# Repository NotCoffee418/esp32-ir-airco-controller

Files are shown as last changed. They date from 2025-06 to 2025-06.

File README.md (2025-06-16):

# ESP32 IR Air Conditioner Controller

A WiFi-enabled ESP32 device that controls Fujitsu air conditioners via infrared commands. Features a web dashboard for manual control, REST API for automation, and automatic WiFi fallback with hotspot configuration.

## What it does

This device replaces your physical AC remote with wireless control:
- **Manual Control**: Web dashboard with temperature, mode, fan speed, and swing controls
- **API Integration**: REST endpoints for home automation systems
- **Status Monitoring**: Real-time temperature readings and AC status
- **WiFi Management**: Automatic hotspot fallback when WiFi connection fails
- **API Key Management**: Secure API access with key generation and management

## Supported AC Models

Tested and confirmed working with:
- **ASHG24KMTA** (24,000 BTU unit) with AR-REW2E remote (0.5°C steps)
- **ASHG09KMCC** (9,000 BTU unit) with AR-REB1E remote (1°C steps)

Uses ARREB1E remote protocol for both units. The project can be modified to support other Fujitsu models or different AC brands by updating the IR command codes.

## Hardware Requirements

📋 **[Complete Shopping List](docs/shopping-list.md)** - All components with supplier links

🔌 **[Pin Layout Guide](docs/module-pins.md)** - Wiring connections and schematic

📦 **[3D Printable Case](models/AircoControllerCase.stl)** - Custom enclosure design

## Software Setup

### Prerequisites
- Visual Studio Code with PlatformIO extension
- ESP32 connected via USB

### Installation
1. **Open Project**: Use PlatformIO Home → Open Project (important: don't just open the folder in VSCode)
2. **Flash Device**: Press `Ctrl+Shift+P` → "PlatformIO: Upload and Monitor"
3. **Monitor Output**: Watch terminal for hotspot credentials and IP information

### Optional Pre-Configuration
Create `airco-controller/data/config.json` based on `airco-controller/data/config_example.json` to flash the device with WiFi credentials and settings pre-configured.

## WiFi & Network Setup

### Automatic Hotspot Fallback
- **Triggers**: No WiFi config OR WiFi connection lost for >30 seconds
- **Hotspot Name & PIN**: Printed on device bottom + shown in terminal during flashing
- **Access Point**: Connect to hotspot and navigate to `192.168.255.1`
- **Dashboard**: Configure WiFi and access all device features

### Normal Operation
Once WiFi is configured, access the dashboard at the device's local IP address (shown in terminal/hotspot setup).

## Web Dashboard Features

- **Manual Controls**: Set temperature, mode (Cool/Heat/Dry/Fan), fan speed, swing, and powerful mode
- **Status Display**: Current temperature, AC state, WiFi connection info
- **API Key Management**: Generate, view, and delete API keys for automation access
- **Quick Actions**: One-click summer/winter mode presets

## REST API

**[Complete API Documentation](https://github.com/NotCoffee418/esp32-ir-airco-controller/blob/main/docs/api-documentation.md)** - Full endpoint reference with examples

Key endpoints:
- `POST /api/ir/off` - Turn off AC
- `POST /api/ir/on` - Turn on with settings (mode, temp, fan, swing)
- `POST /api/ir/toggle-powerful` - Toggle powerful mode
- `GET /api/sensors` - Get temperature and mode status (no auth required)

All control endpoints require API key authentication:
```
Authorization: ApiKey YOUR_API_KEY
```

Generate and manage API keys through the web dashboard.

## Project Structure

- **`airco-controller/`** - Main ESP32 firmware (flash this to your device)
- **`ir-receiver/`** - Test module for capturing IR signals from remotes
- **`docs/`** - Hardware guides and component lists  
- **`models/`** - 3D printable case files

## IR Receiver Test Module

The `ir-receiver/` folder contains a simple test program to capture and decode IR signals from your existing AC remote. Useful for:
- Verifying hardware connections
- Adding support for new AC models
- Debugging IR transmission issues

Flash this first if you want to test your hardware setup before installing the main controller.

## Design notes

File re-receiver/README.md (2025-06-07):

# RE-Receiver

Experimental tool to test and verify IR signals.
Interpret IR signals and display them on a web page. Designed for Fujitsu A/C units.

## Usage

1. PlatformIO vscode extension installed.
2. Configure `data/config.ini` with your WiFi credentials and network settings.
3. Create file system and upload code

    ```bash
    # Only do this once unless full reset
    pio run --target uploadfs
    ```

4. Ctrl+Shift+P -> PlatformIO: Upload and Monitor

## Modules

### TSOP2238 (front view) → ESP32

- Pin 1 (OUT) → GPIO 4
- Pin 2 (VS)  → 3.3V
- Pin 3 (GND) → GND

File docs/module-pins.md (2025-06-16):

# ESP32 AC Controller - Module Connections

## ⚠️ CRITICAL WARNING ⚠️

**ALWAYS VERIFY PIN LAYOUTS WITH THE COMPONENT DATASHEET BEFORE CONNECTING!**

Different manufacturers and model revisions can have completely different pin arrangements, even for components with the same part number. Double-check your specific component's datasheet to avoid damaging your ESP32 or components. When in doubt, use a multimeter to verify connections.

---

## Temperature Sensor

**DS18B20 Waterproof Digital Temperature Sensor**  
[Gotron DS18B20](https://www.gotron.be/waterproof-ds18b20-digital-temperature-sensor-extras.html)

**Connections:**
- Blue wire → GND
- Red wire → VIN (3.3V)
- Yellow wire → D13
- **4.7kΩ pull-up resistor between Red and Yellow wires**

**Soldering Configuration:**
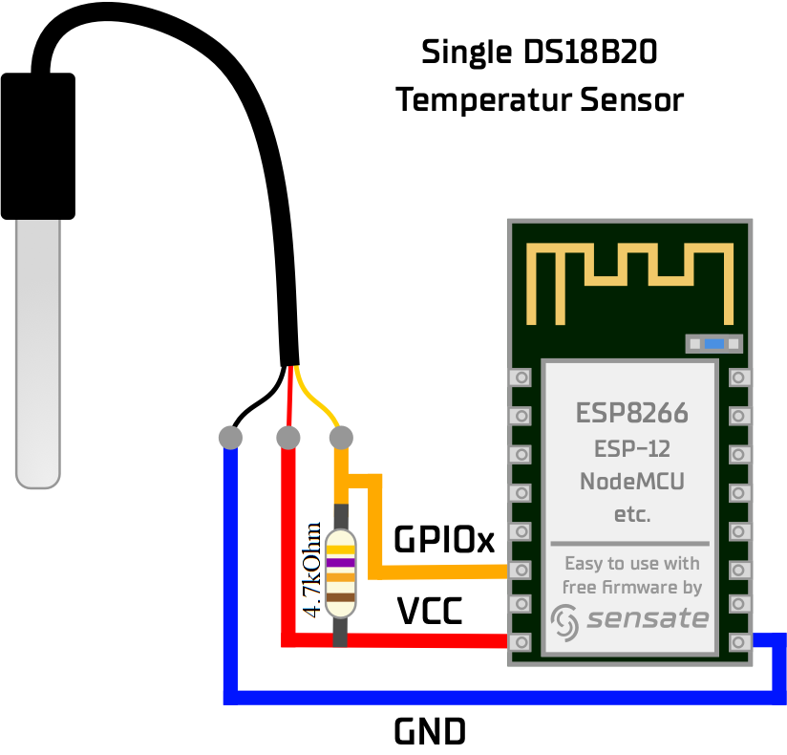
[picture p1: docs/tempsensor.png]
Temperature Sensor Wiring


*The pull-up resistor must be soldered between the red (VIN) and yellow (data) wires as shown above.*

## IR LED Transmitter

**ELIR204 IR LED (940nm, 3mm)**  
[Gotron IR LED](https://www.gotron.be/componenten/actief/opto/zender-ontvanger/ir-led-blauw-35-3mm-940nm-20ma-1-2v.html)

**Connections:**
- Long leg (Anode) → D4 (via 100Ω resistor)
- Short leg (Cathode) → GND

## Mode Switch

**MS100A SPST Toggle Switch (6A, 250V)**  
[Gotron Toggle Switch](https://www.gotron.be/componenten/schakelmat/schakelaars/toestel/toestelschakelaar-enkelpolig-on-off-spst-6a-250v-zwart.html)

**Connections:**
- Pin 1 → GND
- Pin 2 → D12

---

## Ground Connection Notes

**All GND connections from the modules can be combined using:**
- WAGO 5-pole connectors for clean, reusable connections
- Direct soldering for permanent installations

This allows sharing a single GND connection from the ESP32 to all modules requiring ground.

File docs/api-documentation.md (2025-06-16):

# AC Controller API Documentation

## Authentication

Control endpoints require API key authentication:

```
Authorization: ApiKey YOUR_API_KEY
```

API keys can be generated on the device's web dashboard.

**Note:** `/api/sensors` does not require authentication.

## Response Format

**IR Control endpoints** return:
```json
{
  "success": true|false,
  "error": "error message or empty string",
  "data": true|false
}
```

- **data**: `true` = command executed (automatic mode), `false` = command acknowledged but not executed (manual mode)

**Data endpoints** return:
```json
{
  "success": true|false,
  "error": "error message or empty string", 
  "data": { ... }
}
```

## Endpoints

### Turn Off AC

`POST /api/ir/off`

No request body required.

---

### Turn On AC

`POST /api/ir/on`

**Request:**
```json
{
  "mode": 1,
  "fanSpeed": 0,
  "temperature": 23,
  "swing": 1
}
```

**Parameters:**
- **mode** (integer, required):
  - `1`: Cool
  - `2`: Dry (ignores temperature)
  - `3`: Fan (ignores temperature)
  - `4`: Heat
- **fanSpeed** (integer, required):
  - `0`: Auto, `1`: High, `2`: Medium, `3`: Low, `4`: Quiet
- **temperature** (number, required):
  - Cool mode: 18-30°C
  - Heat mode: 16-30°C
  - Dry/Fan modes: ignored
- **swing** (integer, required):
  - `0`: Off, `1`: Vertical

---

### Toggle Powerful Mode

`POST /api/ir/toggle-powerful`

No request body required.

---

### Get Sensor Data

`GET /api/sensors`

**Response:**
```json
{
  "success": true,
  "error": "",
  "data": {
    "temperature": 22.5,
    "isAutomaticMode": true
  }
}
```

## HTTP Status Codes

- **200**: Success
- **400**: Invalid request data
- **401**: Authentication required

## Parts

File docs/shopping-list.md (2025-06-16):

# Shopping List - ESP32 AC Controller (2 Units)

## Microcontroller

**2x NodeMCU ESP32 with USB-C** - €15.90 each  
[Gotron ESP32-C](https://www.gotron.be/esp32-joyit-met-usb-c.html) | [Pin Layout](https://joy-it.net/en/products/SBC-NodeMCU-ESP32-C) | [Manual](https://joy-it.net/files/files/Produkte/SBC-NodeMCU-ESP32-C/SBC-NodeMCU-ESP32-C_Manual-EN_2025-01-17.pdf)

## IR Components

**2x ELIR204 IR LED (940nm, 3mm)** - €0.36 each  
[Gotron IR LED](https://www.gotron.be/componenten/actief/opto/zender-ontvanger/ir-led-blauw-35-3mm-940nm-20ma-1-2v.html)

**2x 100Ω Resistors (1/4W)** - €0.10 each  
[Gotron 100Ω](https://www.gotron.be/ra100-weerstand-1-4w-100-ohm-koolstoffilmlaag.html)  
*Note: Install on positive side only*

## Temperature Sensing

**2x DS18B20 Waterproof Temperature Sensor (includes 4.7kΩ pull-up resistor)** - €11.91 each  
[Gotron DS18B20](https://www.gotron.be/waterproof-ds18b20-digital-temperature-sensor-extras.html)

**2x 4.7kΩ Pull-up Resistors (1/4W)** - €0.10 each  
[Gotron 4.7kΩ](https://www.gotron.be/ra4k7-weerstand-1-4w-4-7-kohm-koolstoffilmlaag.html)  
*Note: Included with DS18B20 sensors at Gotron*

**2x Cable Gland PG7 (Black)** - €0.64 each  
[Gotron Cable Gland](https://www.gotron.be/kabelwartel-zwart-pg7.html)

## Mode Switch

**2x SPST Toggle Switch MS100A (6A, 250V)** - €1.50 each  
[Gotron Toggle Switch](https://www.gotron.be/componenten/schakelmat/schakelaars/toestel/toestelschakelaar-enkelpolig-on-off-spst-6a-250v-zwart.html)

**1x Set Spade Connectors Female 4.8mm (Blue, 10pcs)** - €2.00  
[Gotron Spade Connectors](https://www.gotron.be/opschuifcontact-vrouwelijk-4-8x0-8mm-blauw-10-stuks.html)

## Power Supply

**2x USB Wall Adapter (4W)** - €5.00 each  
[Gotron USB Adapter](https://www.gotron.be/energie/voedingen/gestabiliseerd/usb/usb-voeding-4w.html)  
*Or use any USB adapter you have available*

## Wiring & Connections

**3x Jumper Wire Sets (Female-Female, 15cm, Purple, 10pcs)** - €4.76 each  
[Gotron Jumper Wires](https://www.gotron.be/jumper-wire-paars-female-female-lengte-15cm-10-stuks.html)

**2x WAGO 5-Pole Connector (0.2-4mm², 32A)** - €0.93 each  
[Gotron WAGO Connector](https://www.gotron.be/installatie/installatiemat/verbindingsmateriaal/lusterklemmen/wago-connector-5-polig-0-2-4mm-32a-400v.html)  
*For shared ground connections*

## Hardware

**1x Self-Tapping Screws 2.2x6.5mm (100pcs)** - €5.40  
[Gotron Screws](https://www.gotron.be/installatie/montage/verbindingsmat/diverse/zelftappende-schroef-2-2x6-5mm-100st.html)  
*Plenty for multiple mounting configurations*

---

## Build Notes

- **Quantity**: This list provides components for **2 complete units**
- **IR Range**: ELIR204 LEDs provide sufficient range for typical room installations
- **Power**: USB-C powered units can be powered from any USB adapter or power bank
- **Temperature Sensor**: Waterproof DS18B20 allows external mounting for accurate readings
- **Mode Switch**: Manual/Auto operation toggle for each unit

---

## Total Cost

**Component Breakdown:**
- 2x ESP32 NodeMCU: €31.80
- 2x IR LEDs: €0.72
- 2x 100Ω Resistors: €0.20
- 2x DS18B20 Sensors: €23.82
- 2x 4.7kΩ Resistors: €0.20
- 2x Cable Glands: €1.28
- 2x Toggle Switches: €3.00
- 1x Spade Connectors: €2.00
- 2x USB Adapters: €10.00
- 3x Jumper Wire Sets: €14.28
- 2x WAGO Connectors: €1.86
- 1x Self-Tapping Screws: €5.40

**Total: €94.56**

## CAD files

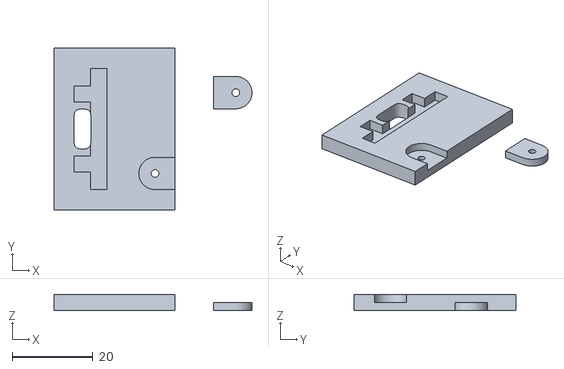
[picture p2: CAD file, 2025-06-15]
models/test_slot_fitting_print.stl
49.0 x 40.0 x 4.00

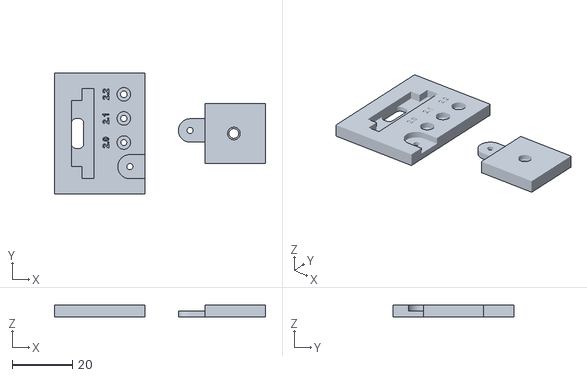
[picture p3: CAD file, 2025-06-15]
models/test3_slot_fitting_print.stl
70.0 x 40.0 x 4.00

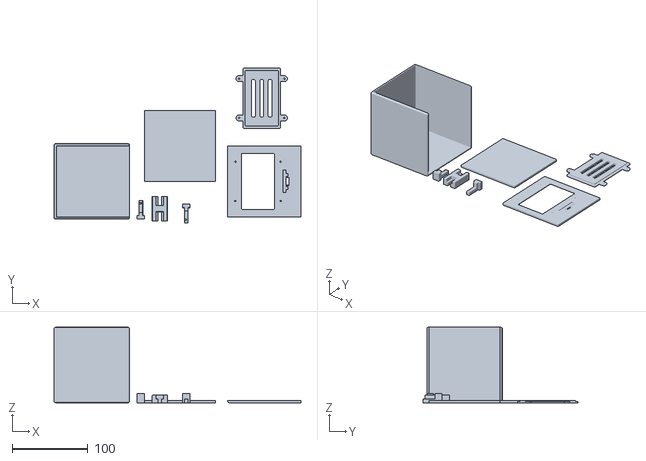
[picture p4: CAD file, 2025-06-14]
models/AircoControllerCase.stl
327.0 x 205.0 x 100.0

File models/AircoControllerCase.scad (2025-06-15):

// FOR FUTURE REFERENCE:
// Don't use OpenSCAD. Software keeps crashing, HQ previews which you need to see holes, are very slow once the model gets bigger.
// Syntax is nice, but everything still quickly turns into a mess.
// CadQuery seems to be the best alternative.

// variable to toggle between printable rotations and visual representation for braining
IS_ASSEMBLED_VIEW = false;

// Disassembles back cover if in assembly view and true
DISASSEMBLE_BACK_COVER = true;

// beginning of board rest levels relative to case floor
board_rest_floor_diff = 20;

// Wall thickness (careful changing this)
wall_thickness = 4;

// USB slot hole size
usbc_slot_width = 9.88;
usbc_slot_height = 4.1;

// Screw hole size (for 6.5mm x 2.2mm with head 1.5)
screw_hole_depth = 7;
screw_head_depth = 1.8;
screw_head_radius = 4.5 / 2; // with 0.4 spacing



// 2.0: resin breaks at regular hole
// 2.05: resin breaks at backplate clip
// 2.1: resin tight fit
// 2.2: resin good
// presumable PLA holes shrink even further, but less breaky.
// Actual screw max diameter seems to be 2.10, and if holes and we can probably handle 0.2 too small in PLA(?)
screw_hole_radius = 2.1 / 2; // resin bre


// Mount block sizes
screw_mount_width = 10;
screw_mount_height = 10;

// 0 is valid, just leaves hole in the back and screw may poke out slighly.
// change freely but be careful of overlapping with other parts.
// 0 is good for checking if hole is positioned right and avoiding weird print issues at angles.
mount_block_back_padding = 0;

// Back cover
back_cover_width = 80;
back_cover_height = 50; // without clips but including cover spacing


// Board actual size
board_width = 28.4;
board_depth = 51.4; // without usbc overhang
board_height = 1.5;

// amount the USBC port sticks out of the board
usbc_port_overhang = 1.5;


// How deep does the device holder slide?
device_holder_single_slot_depth = 12;



// Case Shell without right side
if (!IS_ASSEMBLED_VIEW) {
	// Outer case without floor and back
	translate([0,100,0]) {
	rotate([180,270,0]) {
			outer_case_without_floor_and_back_side();
		}
	}

	// Floor
	translate([120, 50, 0]) {
		floor();
	}

	// case back side
	translate([230,0,0]) {
		outer_case_back_side(); // mind the rounded side!
	}

	// Case removable back cover
	translate([320, 120, 0]) {
		rotate([180, 0, 90]) {
			back_panel_cover();
		}
	}

	// Device holder unit right
	translate([110, 0-30, device_holder_single_slot_depth]) {
		rotate([270, 0, 0]) {
			device_holder_unit(false);
		}
	}

	// Device holder slider bottom
	translate([140, 0, 10]) {
		rotate([180, 0, 0]) {
			device_holder_slider_bottom();
		}
	}

	// Device holder unit left
	translate([180, 20-30, 0]) {
		rotate([90, 0, 0]) {
			device_holder_unit(true);
		}
	}

} else { // Assembled view
	//Outer case without floor and back
	translate([100, 0, 100]) {
		rotate([0, 90, 90]) { 
			outer_case_without_floor_and_back_side();
		}
	}

	// Floor
	translate([wall_thickness , wall_thickness, 0]) {
		floor();
	}

	// case back side
	translate([0,100,100]) {
		rotate([90, 90, 0]) {
			outer_case_back_side(); // mind the rounded side!
		}
	}

	// Case removable back cover
	if (DISASSEMBLE_BACK_COVER) {
		translate([200, 0, 0]) {
			rotate([0, 0, 90]) {
				back_panel_cover();
			}
		}
	} else {
		translate([6, 100, 35]) {
			rotate([90, 0, 0]) {
				back_panel_cover();
			}
		}
	}
	

	// Assembled device holder and spoof board
	translate([34.92,57.1,0]) {
		rotate([0,0,270]) {
			assembled_device_holder(true);
		}		
	}
}


//test_print_pieces();


module floor() {
	center = 100 / 2;

	// Distance from center of case to mount block
	// 0 should be center, 50 should just outside of case
	// this is reference for correct case holes.
	center_offset_pos = 25;

	// Floor
	difference() {
		// Floor block
		cube([100-wall_thickness*2,100-wall_thickness*2,wall_thickness]);

		// Screw hole device mount 1
		// lazy measure
		translate([
			47.07,
			56.6,
			wall_thickness]
		) {
			rotate([180,0,0]) {
				screw_head_hole();
			}
		}

		// Screw hole device mount 2
		// lazy measure
		translate([
			47.07,
			29.6,
			wall_thickness]
		) {
			rotate([180,0,0]) {
				screw_head_hole();
			}
		}		
	}

	

	// Mount block - right frontish
	translate([100-wall_thickness*2, center-center_offset_pos - screw_mount_width, wall_thickness]) {
		rotate([0, 0, 90]) {
			screw_mount_block();
		}
	}

	// Mount block - right side backish
	translate([100-wall_thickness*2, center+center_offset_pos-screw_mount_width+wall_thickness/2, wall_thickness]) {
		rotate([0, 0, 90]) {
			screw_mount_block();
		}
	}

	// Mount block - left side frontish
	translate([0, center - center_offset_pos, wall_thickness]) {
		rotate([0, 0, 270]) {
			screw_mount_block();
		}
	}


	// Mount block - left side backish
	translate([0, center + center_offset_pos + wall_thickness/2, wall_thickness]) {
		rotate([0, 0, 270]) {
			screw_mount_block();
		}
	}

	// Mount block - back side rightish
	translate([center-center_offset_pos, 100-wall_thickness*2, wall_thickness]) {
		rotate([0, 0, 180]) {
			screw_mount_block();
		}
	}

	// Mount block - back side left
	translate([center+center_offset_pos+wall_thickness/2, 100-wall_thickness*2, wall_thickness]) {
		rotate([0, 0, 180]) {
			screw_mount_block();
		}
	}

}



// 8 wide
// with_difference_hole: 
// true: simulates a screw (used to difference in case)
// false: actual hole as visible
module backplate_screw_hole_holder(x, y, z, with_difference_hole=true) {
	case_clip_width = 8;
	plate_clip_width = 7.6;
	clip_width = with_difference_hole ? plate_clip_width : case_clip_width;
	x_offset = !with_difference_hole ? 0 : (case_clip_width - plate_clip_width) / 2;

	translate([x+x_offset,y+5,z]) {
		linear_extrude(height=wall_thickness/2) { 
			difference() {
				union() {
					square([clip_width, 5.5]); // Attahment clip square part
					translate([clip_width/2, 0, 0]) // Attachment clip round part
						circle(r=clip_width/2, $fn=100);

				}
				if (with_difference_hole) {
					translate([clip_width/2, 0, 0])
						circle(r=screw_hole_radius, $fn=50); // Screw hole
				}
			}
			
		}
		if (!with_difference_hole) {
			translate([clip_width/2, 0, 0]) {
				linear_extrude(height=wall_thickness) {
					circle(r=screw_hole_radius, $fn=50); // Screw hole
				}
			}
		}
	}
}


// is_true_panel: true: actual panel, false: difference hole
module back_panel_cover(is_true_panel=true) {
	cover_slot_spacing = 3;
	corner_radius = 1.5;
	layer_height = wall_thickness/2;

	clearance_offset = 0.4;

	size_offset = is_true_panel ? clearance_offset : 0;
	
	translate([cover_slot_spacing+corner_radius/2,0,0]) { // dontk now why, dont care.
		difference() {
			// Back cover panel
			union() {
				// Outer Layer
				rounded_square_wall(
					[size_offset/2, size_offset/2, 0], 
					[back_cover_width-size_offset, back_cover_height-size_offset, layer_height], 
					corner_radius); // bot layer (bigger)

				// Inner Layer
				// Hide on true cover, but use for difference hole
				if (!is_true_panel) {
					rounded_square_wall(
						[cover_slot_spacing, cover_slot_spacing, layer_height],
						[back_cover_width-cover_slot_spacing*2, back_cover_height-cover_slot_spacing*2,layer_height], 
						corner_radius); // top layer
				}
				backplate_screw_hole_holder(10, -10, 0, is_true_panel);
				backplate_screw_hole_holder(62, -10, 0, is_true_panel);
				translate([80, 60, 0]) {
					rotate([0, 0, 180]) {
						backplate_screw_hole_holder(10, 0, 0, is_true_panel);
						backplate_screw_hole_holder(62, 0, 0, is_true_panel);
					}
				}
			}
			// Air vents
			if (is_true_panel) {
				union() {
					translate([15,11.5,0]) {
						air_vent();
					}
					translate([15,22.5,0]) {
						air_vent();
					}
					translate([15,33.5,0]) {
						air_vent();
					}
				}
			}
		}
	}
}


module outer_case_without_floor_and_back_side() {
	
	// Mount screw hole relative positions
	screw_hole_pos_and_rot = get_mount_screw_head_hole_pos_and_rot();
	shx = screw_hole_pos_and_rot[0][0];
	shy = screw_hole_pos_and_rot[0][1];
	shz = screw_hole_pos_and_rot[0][2];
	shrotx = screw_hole_pos_and_rot[1][0];
	shroty = screw_hole_pos_and_rot[1][1];
	shrotz = screw_hole_pos_and_rot[1][2];

	center = 100 / 2;

	// why 1? no clue, but it works.
	screw_pos_center_offset = 25 + 1;

	difference() {
		// Box boxy
		rounded_cube([100, 100, 100], 2);

		// Inner cavity 3mm wall thickness
		translate([wall_thickness, wall_thickness, wall_thickness])
			cube([100-wall_thickness, 100-wall_thickness*2, 100-wall_thickness]);


		// Screw holes right side (front sided)
		translate([100-wall_thickness-shx, shy, center-screw_pos_center_offset]) {
			rotate([shrotx, shroty, shrotz]) {
				screw_head_hole();
			}
		}

		// Screw holes right side (back sided)
		translate([100-wall_thickness-shx, shy, center+screw_pos_center_offset]) {
			rotate([shrotx, shroty, shrotz]) {
				screw_head_hole();
			}
		}
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

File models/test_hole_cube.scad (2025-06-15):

screw_hole_radius = 1.9 / 2;

difference() {
	rounded_cube([20,20,20],3);
	translate([10,10,0]) {
		screw_hole(20);
	}
	rotate([0, 90, 0]) {
		translate([-10,10,0]) {
			screw_hole(20);
		}
	}

	rotate([0, 90, 90]) {
		translate([-10,-10,0]) {
			screw_hole(20);
		}
	}	
}

module screw_hole(depth) {
	linear_extrude(height=depth) {
		circle(r=screw_hole_radius, $fn=20);
	}
}

module rounded_cube(size, radius) {
    translate([radius, radius, radius])  // shift to correct position
        minkowski() {
            cube([size[0]-2*radius, size[1]-2*radius, size[2]-2*radius]);
            sphere(r=radius, $fn=50*radius);
        }
}

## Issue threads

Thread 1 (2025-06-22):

IR signals break on dry mode

NotCoffee418, 2025-06-22:
Attempting to set AC to dry prevents new IR signals from sending until box is restarted.
Likely some sort of soft crash from disallowed settings (any temperature defined?) causing it to think we are still emitting signal.
Possibly coincidence, but we'll find out if it's consistently a problem.

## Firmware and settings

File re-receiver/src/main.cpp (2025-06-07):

#include <Arduino.h>
#include <WiFi.h>
#include <WebServer.h>
#include <IRremoteESP8266.h>
#include <IRrecv.h>
#include <IRutils.h>
#include <ArduinoJson.h>
#include <ir_Fujitsu.h>
#include <LittleFS.h>

// WiFi credentials - will be loaded from config.ini
String wifi_ssid = "YOUR_WIFI_SSID";
String wifi_password = "YOUR_WIFI_PASSWORD";
String config_static_ip = "192.168.50.201";
String config_gateway = "192.168.50.1";

// Static IP configuration
IPAddress local_IP(192, 168, 50, 201);
IPAddress gateway(192, 168, 50, 1);      // Usually your router IP
IPAddress subnet(255, 255, 255, 0);
IPAddress primaryDNS(8, 8, 8, 8);       // Google DNS
IPAddress secondaryDNS(8, 8, 4, 4);

// IR receiver setup
const uint16_t IR_RECV_PIN = 4;  // GPIO4
const uint16_t CAPTURE_BUFFER_SIZE = 1024;
const uint8_t TIMEOUT = 50;  // Longer timeout to catch multiple frames
const uint32_t FRAME_COLLECTION_TIME = 3000;  // Collect frames for 3 seconds
unsigned long lastDecodeTime = 0;

IRrecv irrecv(IR_RECV_PIN, CAPTURE_BUFFER_SIZE, TIMEOUT, true);
decode_results results;
WebServer server(80);

// Function prototypes (tells compiler these functions exist)
void handleRoot();
void handleLastSignal();
void handleStatus();
void handleNotFound();
void loadConfig();

// Store last received IR signal with decoded data
struct IRSignal {
    String protocol;
    std::vector<uint64_t> values;
    std::vector<uint16_t> bits;
    String decodedData;
    String modelInfo;
    String rawData;
    unsigned long timestamp;
    bool hasData;
    bool hasDecodedData;
    int frameCount;
} lastSignal = {"", {}, {}, "", "", "", 0, false, false, 0};

void setup() {
    Serial.begin(115200);
    Serial.println("Starting IR HTTP Server...");
    
    // Try to initialize filesystem, but don't worry if it fails
    if (LittleFS.begin(true)) {
        Serial.println("LittleFS mounted successfully");
        loadConfig();
    } else {
        Serial.println("LittleFS not available, using hardcoded defaults");
    }
    
    // If still using defaults, you can hardcode your WiFi here temporarily
    if (wifi_ssid == "YOUR_WIFI_SSID") {
        wifi_ssid = "YourActualSSID";           // Put your real SSID here
        wifi_password = "YourActualPassword";   // Put your real password here
        Serial.println("Using hardcoded WiFi credentials");
    }
    
    // Initialize IR receiver
    irrecv.enableIRIn();
    Serial.println("IR Receiver enabled on GPIO " + String(IR_RECV_PIN));
    
    // Configure static IP
    if (!WiFi.config(local_IP, gateway, subnet, primaryDNS, secondaryDNS)) {
        Serial.println("Failed to configure static IP");
    }
    
    // Connect to WiFi
    WiFi.begin(wifi_ssid.c_str(), wifi_password.c_str());
    Serial.print("Connecting to WiFi: " + wifi_ssid);
    
    while (WiFi.status() != WL_CONNECTED) {
        delay(500);
        Serial.print(".");
    }
    
    Serial.println();
    Serial.println("WiFi connected!");
    Serial.print("IP address: ");
    Serial.println(WiFi.localIP());
    
    // Setup HTTP endpoints
    server.on("/", handleRoot);
    server.on("/last-signal", handleLastSignal);
    server.on("/status", handleStatus);
    server.onNotFound(handleNotFound);
    
    server.begin();
    Serial.println("HTTP server started");
    Serial.println("Endpoints:");
    Serial.println("  GET / - Web interface");
    Serial.println("  GET /last-signal - JSON with last IR signal");
    Serial.println("  GET /status - System status");
}

void loop() {
    // Handle HTTP requests
    server.handleClient();
    
    // Check for IR signals
    if (irrecv.decode(&results)) {
        unsigned long now = millis();
        
        // If this is a new protocol or too much time passed, start fresh  
        if (lastSignal.protocol != typeToString(results.decode_type) || 
            (now - lastDecodeTime) > FRAME_COLLECTION_TIME) {
            
            lastSignal.protocol = typeToString(results.decode_type);
            lastSignal.values.clear();
            lastSignal.bits.clear();
            lastSignal.frameCount = 0;
            lastSignal.rawData = "";
            lastSignal.decodedData = "";
            lastSignal.modelInfo = "";
            lastSignal.hasDecodedData = false;
            Serial.println("=== Starting new IR sequence ===");
        }
        
        // Add this frame to the sequence
        lastSignal.values.push_back(results.value);  // Keep for compatibility
        lastSignal.bits.push_back(results.bits);
        lastSignal.frameCount++;
        lastSignal.hasData = true;
        lastSignal.timestamp = now;
        lastDecodeTime = now;
        
        // Capture FULL hex data from state array (not just results.value)
        String fullHex = "0x";
        for (int i = results.bits / 8 - 1; i >= 0; i--) {  // Big endian
            if (results.state[i] < 16) fullHex += "0";
            fullHex += String(results.state[i], HEX);
        }
        
        // Also create little endian version to compare
        String fullHexLE = "0x";
        for (int i = 0; i < results.bits / 8; i++) {  // Little endian
            if (results.state[i] < 16) fullHexLE += "0";
            fullHexLE += String(results.state[i], HEX);
        }
        
        // Update raw data with full hex
        if (lastSignal.frameCount > 1) lastSignal.rawData += " | ";
        lastSignal.rawData += "Frame" + String(lastSignal.frameCount) + ": " + fullHex + " (" + String(results.bits) + " bits)";
        
        // Print to serial for debugging
        Serial.println("=== IR Frame " + String(lastSignal.frameCount) + " ===");
        Serial.println("Protocol: " + lastSignal.protocol);
        Serial.println("Full Hex BE (" + String(results.bits) + " bits): " + fullHex);
        Serial.println("Full Hex LE (" + String(results.bits) + " bits): " + fullHexLE);
        Serial.println("Partial (results.value): 0x" + String(results.value, HEX));
        Serial.println("Gap since last: " + String(now - lastDecodeTime) + "ms");
        
        // Show byte-by-byte breakdown
        Serial.print("State bytes: ");
        for (uint16_t i = 0; i < results.bits / 8; i++) {
            if (results.state[i] < 16) Serial.print("0");
            Serial.print(results.state[i], HEX);
            Serial.print(" ");
        }
        Serial.println();
        
        // Try to decode EVERY frame as Fujitsu AC to see what the library sees
        if (lastSignal.protocol == "FUJITSU_AC") {
            Serial.println("=== Attempting Fujitsu AC decode on this frame ===");
            
            IRFujitsuAC ac(0);
            if (ac.validChecksum(results.state, results.bits / 8)) {
                ac.setRaw(results.state, results.bits / 8);
                
                Serial.println("DECODE SUCCESS for Frame " + String(lastSignal.frameCount) + ":");
                Serial.println("Power: " + String(ac.getPower() ? "ON" : "OFF"));
                Serial.println("Mode: " + String(ac.getMode()));
                Serial.println("Temperature: " + String(ac.getTemp()) + "°C");
                Serial.println("Fan Speed: " + String(ac.getFanSpeed()));
                Serial.println("Swing: " + String(ac.getSwing()));
                
                // Store the LATEST successful decode
                lastSignal.decodedData = "Power: " + String(ac.getPower() ? "ON" : "OFF") + 
                                       " | Mode: " + String(ac.getMode()) + 
                                       " | Temp: " + String(ac.getTemp()) + "°C" +
                                       " | Fan: " + String(ac.getFanSpeed()) +
                                       " | Swing: " + String(ac.getSwing()) +
                                       " | Model: " + String(ac.getModel()) +
                                       " | Frame: " + String(lastSignal.frameCount);
                
                // Extract model info for web display from the full toString() output
                String fullStateString = ac.toString();
                int modelStart = fullStateString.indexOf("Model: ");
                if (modelStart != -1) {
                    int modelEnd = fullStateString.indexOf(",", modelStart);
                    if (modelEnd != -1) {
                        lastSignal.modelInfo = fullStateString.substring(modelStart + 7, modelEnd); // Skip "Model: "
                    } else {
                        lastSignal.modelInfo = "Model " + String(ac.getModel());
                    }
                } else {
                    lastSignal.modelInfo = "Model " + String(ac.getModel());
                }
                
                lastSignal.hasDecodedData = true;
            } else {
                Serial.println("DECODE FAILED for Frame " + String(lastSignal.frameCount) + " (bad checksum)");
            }
        }
        
        Serial.println();
        
        // Resume receiving
        irrecv.resume();
    }
    
    delay(50);  // Small delay to prevent overwhelming the loop
}

void handleRoot() {
    String html = R"rawliteral(
<!DOCTYPE html>
<html>
<head>
    <title>ESP32 IR Receiver</title>
    <meta name="viewport" content="width=device-width, initial-scale=1">
    <style>
        body { font-family: Arial; margin: 40px; background: #f0f0f0; }
        .container { background: white; padding: 20px; border-radius: 8px; box-shadow: 0 2px 10px rgba(0,0,0,0.1); }
        .signal { background: #e8f4fd; padding: 15px; border-radius: 5px; margin: 10px 0; }
        .decoded { background: #e8f8e8; padding: 12px; border-radius: 5px; margin: 8px 0; border-left: 4px solid #4CAF50; }
        .technical { background: #f8f8f8; padding: 10px; border-radius: 5px; margin: 8px 0; font-family: monospace; font-size: 0.9em; }
        .timestamp { color: #666; font-size: 0.9em; }
        .stats { display: flex; gap: 15px; margin: 10px 0; }
        .stat { background: #fff; padding: 8px 12px; border-radius: 4px; border: 1px solid #ddd; }
        .note { margin-top: 10px; font-size: 0.8em; color: #888; font-style: italic; }
        button { background: #007cba; color: white; border: none; padding: 10px 20px; border-radius: 5px; cursor: pointer; }
        button:hover { background: #005a87; }
    </style>
</head>
<body>
    <div class="container">
        <h1 id="pageTitle">ESP32 IR Receiver</h1>
        <p>Point your remote at the receiver and press any button!</p>
        
        <button onclick="refreshSignal()">Refresh Last Signal</button>
        
        <div id="lastSignal">
            <h3>Last Signal:</h3>
            <div id="signalData">No signal received yet...</div>
        </div>
    </div>

    <script>
        function refreshSignal() {
            fetch('/last-signal')
                .then(response => response.json())
                .then(data => {
                    const signalDiv = document.getElementById('signalData');
                    if (data.hasData) {
                        // Update page title with model info
                        const titleElement = document.getElementById('pageTitle');
                        if (data.modelInfo) {
                            titleElement.textContent = `ESP32 IR Receiver - Fujitsu ${data.modelInfo}`;
                        } else {
                            titleElement.textContent = `ESP32 IR Receiver - ${data.protocol}`;
                        }
                        
                        let html = `
                            <div class="signal">
                                <strong>Protocol:</strong> ${data.protocol}
                                <div class="timestamp">Received: ${new Date(data.timestamp).toLocaleString()}</div>
                            </div>
                        `;
                        
                        if (data.hasDecodedData) {
                            html += `
                                <div class="decoded">
                                    <strong>Decoded AC Settings:</strong><br>
                                    ${data.decodedData.replace(/\|/g, '<br>')}
                                </div>
                            `;
                        }
                        
                        html += `
                            <div class="stats">
                                <div class="stat"><strong>Frames:</strong> ${data.frameCount}</div>
                                <div class="stat"><strong>Frequency:</strong> ${data.frequency || '38kHz'}</div>
                                <div class="stat"><strong>Signal:</strong> ${data.signalStrength || 'Good'}</div>
                                <div class="stat"><strong>Total Bits:</strong> ${data.frames.reduce((sum, frame) => sum + frame.bits, 0)}</div>
                            </div>
                        `;
                        
                        html += `<div class="technical"><strong>Technical Details:</strong><br>`;
                        html += `${data.rawData || 'No raw data available'}<br>`;
                        html += `<br><strong>Frame Breakdown:</strong><br>`;
                        data.frames.forEach((frame, index) => {
                            html += `Frame ${index + 1}: ${frame.valueHex} (${frame.bits} bits - partial view)<br>`;
                        });
                        html += `</div>`;
                        
                        html += `
                            <div class="note">
                                Tip: Try changing temperature, mode, or fan speed on your remote to see live updates!
                            </div>
                        `;
                        
                        signalDiv.innerHTML = html;
                    } else {
                        signalDiv.innerHTML = 'No signal received yet...';
                    }
                })
                .catch(err => console.error('Error:', err));
        }
        
        // Auto-refresh every 2 seconds
        setInterval(refreshSignal, 2000);
        
        // Initial load
        refreshSignal();
    </script>
</body>
</html>
    )rawliteral";
    
    server.send(200, "text/html", html);
}

void handleLastSignal() {
    JsonDocument doc;
    
    if (lastSignal.hasData) {
        doc["hasData"] = true;
        doc["protocol"] = lastSignal.protocol;
        doc["timestamp"] = lastSignal.timestamp;
        doc["frameCount"] = lastSignal.frameCount;
        doc["decodedData"] = lastSignal.decodedData;
        doc["hasDecodedData"] = lastSignal.hasDecodedData;
        doc["modelInfo"] = lastSignal.modelInfo;
        doc["rawData"] = lastSignal.rawData;
        doc["signalStrength"] = "Strong";
        doc["frequency"] = "38kHz";
        
        JsonArray frames = doc["frames"].to<JsonArray>();
        for (int i = 0; i < lastSignal.frameCount; i++) {
            JsonObject frame = frames.add<JsonObject>();
            frame["value"] = lastSignal.values[i];
            frame["valueHex"] = "0x" + String(lastSignal.values[i], HEX);
            frame["bits"] = lastSignal.bits[i];
        }
    } else {
        doc["hasData"] = false;
        doc["message"] = "No IR signal received yet";
    }
    
    String jsonString;
    serializeJson(doc, jsonString);
    
    server.send(200, "application/json", jsonString);
}

void handleStatus() {
    JsonDocument doc;
    doc["uptime"] = millis();
    doc["freeHeap"] = ESP.getFreeHeap();
    doc["wifiStatus"] = WiFi.status();
    doc["ipAddress"] = WiFi.localIP().toString();
    doc["irReceiverPin"] = IR_RECV_PIN;
    
    String jsonString;
    serializeJson(doc, jsonString);
    
    server.send(200, "application/json", jsonString);
}

void handleNotFound() {
    server.send(404, "text/plain", "404 Not Found");
}

void loadConfig() {
    if (!LittleFS.exists("/config.ini")) {
        Serial.println("Config file (config.ini) not found, using defaults");
        return;
    }
    
    File configFile = LittleFS.open("/config.ini", "r");
    if (!configFile) {
        Serial.println("Failed to open config.ini");
        return;
    }
    
    String currentSection = "";
    
    while (configFile.available()) {
        String line = configFile.readStringUntil('\n');
        line.trim();
        
        // Skip empty lines and comments
        if (line.length() == 0 || line.startsWith("#") || line.startsWith(";")) {
            continue;
        }
        
        // Check for section headers [section]
        if (line.startsWith("[") && line.endsWith("]")) {
            currentSection = line.substring(1, line.length() - 1);
            Serial.println("Reading section: " + currentSection);
            continue;
        }
        
        // Parse key = value pairs
        int equalPos = line.indexOf('=');
        if (equalPos > 0) {
            String key = line.substring(0, equalPos);
            String value = line.substring(equalPos + 1);
            key.trim();
            value.trim();
            
            // Remove quotes if present
            if (value.startsWith("\"") && value.endsWith("\"")) {
                value = value.substring(1, value.length() - 1);
            }
            
            // Process based on section and key
            if (currentSection == "wifi") {
                if (key == "ssid") {
                    wifi_ssid = value;
                    Serial.println("Loaded SSID: " + wifi_ssid);
                } else if (key == "password") {
                    wifi_password = value;
                    Serial.println("Loaded WiFi password");
                }
            } else if (currentSection == "network") {
                if (key == "static_ip") {
                    config_static_ip = value;
                    Serial.println("Loaded static IP: " + config_static_ip);
                } else if (key == "gateway") {
                    config_gateway = value;
                    Serial.println("Loaded gateway: " + config_gateway);
                }
            }
        }
    }
    
    configFile.close();
    Serial.println("Config loaded successfully from config.ini");
}

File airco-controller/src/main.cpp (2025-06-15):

#include <Arduino.h>
#include <LittleFS.h>
#include <WiFi.h>

#include "web/server.h"
#include "network/device_identity.h"
#include "network/wifi_provisioning.h"
#include "storage/config.h"
#include "diagnostic.h"
#include "storage/config.h"
#include "modules/temperature.h"
#include "modules/ir_remote.h"
#include "modules/mode_switch.h"

// private constants
const unsigned long _WIFI_HEALTH_CHECK_INTERVAL_MS = 30000;

// Global private variables
static bool _inHotspotMode = false;
static unsigned long _lastWifiHealthCheck = 0;

void setup() {
	// Initialize serial communication
	Serial.begin(115200);
	Serial.println("Booting Airco Control Unit...");

	// Wait for everything to wake up 
	// wifi sometimes won't connect without this
	delay(3000);

	// Try to initialize filesystem, but don't worry if it fails
    if (!LittleFS.begin(true)) {
		Serial.println("Error mounting LittleFS");
		delay(1000);
		ESP.restart();
		return;
    }

	// Load config
	Config config;
	getConfig(config);

	// Set WiFi to persistent mode to off (applies to all modes).
	// Prevents using old credentials despite explicitly defining them otherwise.
	// Persists between flashes and reboots in magic storage we do not want..
	// Manual wipe: esptool.py --chip esp32 erase_region 0x9000 0x6000
	WiFi.persistent(false);

	// Setup WiFi
	_inHotspotMode = config.bootInHotspotMode;
	if (_inHotspotMode) {
		startHotspot();
	} else {
		Serial.println("Requesting connection to SSID: " + String(config.ssid));
		bool connected = startWifiConnection(true);
		if (!connected) {
			Serial.println("WiFi: Failed to connect. Rebooting in hotspot mode.");
			setBootInHotspotMode(true);
			delay(1000);
			ESP.restart();
			return;
		}
	}

	// Setup web server (Requires an IP address)
	webServerSetup(_inHotspotMode);

	// setup modules
	setupTemperatureSensor();
	setupIrRemote();
	setupModeSwitch();

	// Report device identity
	Serial.println("MAC Address: " + String(WiFi.macAddress()));
	Serial.println("Hotspot name: " + getSetupHotspotName());
	Serial.println("Admin PIN: " + getAccessPin());
	printDiagnosticData();
}

void loop() {
	// bool modeSwitchState = isModeSwitchOnAuto();
	// Serial.println("Mode switch state: " + String(modeSwitchState));

	if (_inHotspotMode) {
	// Handle web and hotspot DNS requests
		handleHotspotDnsRequests();
	}

	// Periodic WiFi health check in all modes
	// Will restart in correct mode if needed
	if (millis() - _lastWifiHealthCheck > _WIFI_HEALTH_CHECK_INTERVAL_MS) {
		Serial.println("Health check at " + String(millis()));
		WifiState wifiState = determineWifiState();
		switch (wifiState) {
			case WIFI_CONNECTED:
				Serial.println("WiFi: ok");
				break;
			case WIFI_HOTSPOT_MODE:
				Serial.println("WiFi: hotspot mode");
				break;
			default:
				Serial.println("WiFi: unknown state");
				break;
		}

		// Print system stats
		printDiagnosticData();

		// Get fresh temperature reading and report it
		// Not just for health check, we also use this to update cached value.
		float tempC = getFreshTempC();
		Serial.println("Temperature Sensor: " + String(tempC));

		// Reset timer
		_lastWifiHealthCheck = millis();
	}

	// Handle web requests
	handleWebRequests();
}

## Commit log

2025-06-07 Temp wifi + web server
    - sketchy fs upload system (best i could do, prebuild glitchy)
    - water.css
    - stream load files from fs allowing "larger" files to exist without hurting ram
    [main.cpp]
2025-06-07 impl hotspot unique identifier per device
    report it on startup for easy access to label on hardware.
    intended light security allowing redefining wifi access point to connect to if old credentials become invalidated
    - witch to #pragma once in headers
2025-06-08 configure page (not secure yet)
    - no validation yet
    - change throws to print messages otherwise we just get hex crap
2025-06-08 implement startWifiConnection()
    - indicate connection success on configure page
    - force setBootInHotspotMode(true) if updated config is invalid
    - prevent duplicate config submission
    [main.cpp, wifi_provisioning.cpp]
2025-06-09 Temperatur sensor
2025-06-09 Both ACs work (and with swing)
    - documented tests
    - 3s delay on boot for wifi to be ready
    - print ssid we connect to
    - delete old temp_wifi_setup
2025-06-09 Safety on IR sends
    - Small delay before IR commands to settle background tasks
    - Disable interrupts (background stuff can't break our very time sensitive command)
    - prevent multiple commands running at the same time
    [ir_remote.cpp]
2025-06-09 Temperature sensor reading caching
    can still be called on request, or with larger interval. Sensor reading takes 750ms (apparently)
2025-06-13 Mode Switch test
2025-06-13 case model: device_holder_slider_bottom
    [AircoControllerCase.scad]
2025-06-13 work on device_holder_unit
    [AircoControllerCase.scad]
2025-06-13 model: rounded edges
    [AircoControllerCase.scad]
2025-06-13 model seperate back+bottom, holder slot
    [AircoControllerCase.scad]
2025-06-13 model: clean up rounded case back/bottom
    [AircoControllerCase.scad]
2025-06-13 model: backpanel cover
    [AircoControllerCase.scad]
2025-06-13 model: back panel cover slot
    [AircoControllerCase.scad]
2025-06-13 model: air vents in back cover
    [AircoControllerCase.scad]
2025-06-13 model: usb-c slot with holder + organize components
    more print friendly rotation on each object
    [AircoControllerCase.scad]
2025-06-13 model: add printable floor
    - bit of cleaning
    [AircoControllerCase.scad]
2025-06-14 model: scattered minor fixes
    [AircoControllerCase.scad]
2025-06-14 wip switching os
    keeps crashing on linux QQ
    [AircoControllerCase.scad, AircoControllerCase.stl]
2025-06-14 model: screw mount pieces + attach to floor sides
    [AircoControllerCase.scad]
2025-06-14 test hole cube (printer vibecheck)
    [test_hole_cube.scad]
2025-06-14 model: restructure functions + screw_head_hole
    [AircoControllerCase.scad]
2025-06-14 model: case to floor screw holes
    screw_mount_block() factors in head depth
    [AircoControllerCase.scad]
2025-06-14 model: rework floor mounts as correct reference
    [AircoControllerCase.scad]
2025-06-14 model: adjust case holes
    - work on backpanel with new thickness
    [AircoControllerCase.scad]
2025-06-14 model: back panel round correct side
    [AircoControllerCase.scad]
2025-06-14 model: fix back cover
    proper center, Z position is still sketch, need to do USB and board slots first to fix it.
    [AircoControllerCase.scad]
2025-06-14 model: fix back plate board holder
    [AircoControllerCase.scad]
2025-06-14 model: assembled holder + spoof board
    [AircoControllerCase.scad]
2025-06-14 model: positioned assembled device holder
    + slot hole and clipping test piece
    [AircoControllerCase.scad, test_slot_fitting_print.stl]
2025-06-14 model: clean up print view + rename to IS_ASSEMBLED_VIEW
    [AircoControllerCase.scad]
2025-06-14 model: screw mounts for device_holder_slider
    [AircoControllerCase.scad]
2025-06-15 model: screw holes for slide slot mounts
    - move unassembled view parts to avoid squeezing mount blocks
    [AircoControllerCase.scad]
2025-06-15 model: temperature sensor hole
    [AircoControllerCase.scad]
2025-06-15 model: fix usbc_slot_with_holder fitting
    - usb position closer to board
    - single padding for buttons and rests usbc
    - padding adjusted based on test print results
    - new test print plate WIP
    [AircoControllerCase.scad]
2025-06-15 model: slight offset on case holder clips
    [AircoControllerCase.scad]
2025-06-15 model: ir slot + test print 3
    [AircoControllerCase.scad, test3_slot_fitting_print.stl]
2025-06-15 model: ir hole in case
    - fix weird ir hole offsets
    [AircoControllerCase.scad]
2025-06-15 model: mode switch hole + in case
    [AircoControllerCase.scad]
2025-06-15 model: back cover clearance
    [AircoControllerCase.scad]
2025-06-15 model: cover clips match cover clearance
    [AircoControllerCase.scad]
2025-06-15 model: increase hole sizes
    - mode slot hole was too big
    [AircoControllerCase.scad]
2025-06-15 case done
    [AircoControllerCase.scad]
2025-06-15 model: missing mount blocks
    - include mount blockback of case to top
    [AircoControllerCase.scad]
2025-06-15 api management endpoints (ujntested)
    [AircoControllerCase.scad]
2025-06-16 web: api key management page
    - Status panel: sensor temperature and device identifier, cleaner temperature display
2025-06-16 status page: current mode
2025-06-16 allow custom AC settings
    - setPowerful AC added
    - authorizeWebOrApiHandler() added and authorizeApiHandler provides proper fail response.
    [ir_remote.cpp]
2025-06-16 page: manual AC control + all api endpoints (probably)
    - powerful is now togglePowerful to reflect how the ac actually works.
    - API docs added
